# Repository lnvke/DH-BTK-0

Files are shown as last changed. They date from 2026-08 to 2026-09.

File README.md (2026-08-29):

# DH-BTK-0
Bluetooth keyboard HID device.

Made this so I can have a wireless keyboard while practicing with ESP-IDF BLE. Split would have given me the opportunity to work with peripheral bluetooth and non-HID communications, something I have never done before.

This is a custom integrated ESP32-C6 SoM based split keyboard using RMK rust mechanical keyboard firmware. Because Zephyr RTOS support for the ESP32-C6 is limited, ZMK firmware is not a viable choice for this project, as the HID (human interface) over GATT protocol has been documented to have conflicts between NimBLE and proprietary Espressif BLE controllers. RMK uses TrouBLE, a rust-based BLE host stack for bluetooth general functionality, which allows for direct interface with esp-radio, taking the role of the connecting link between TrouBLE and the internal host controller interface for bluetooth.
CAD:
https://cad.onshape.com/documents/ec01e30260fb570aa777a2a3 


PCB/Schematic:


(higher quality in SVG)

To make this for yourself, simply download the gerber files found in the production folder (seen as zip files) and export to your fab of choice. I used JLCPCB here. This PCB was designed to be completely double-sided and interchangeable, as to cut down on PCB manufacturing costs. Using JLCPCB's PCB fab MOQ of 5, you can make up to 2 of these keyboards given you have enough components.

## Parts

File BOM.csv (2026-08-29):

item | link | reason | cost | count
u.FL to SMA | https://www.amazon.com/dp/B0D29JTYPK | antenna connector | $7.19 | 5
RP-SMA | https://www.amazon.com/dp/B09KLR18H5/ | antenna | $6.99 | 2
switches | https://www.amazon.com/dp/B0GV2FGCPX/ | for switching | $13.90 | 72
sockets | https://www.amazon.com/dp/B0BVH64NXR | for hotswapping | $10.99 | 70
keycaps | https://www.amazon.com/dp/B0F6L7QTG5/ | so i can press them | $12.99 | 121
Samsung Electro-Mechanics CL21B106KOQNNNE | https://www.lcsc.com/product-detail/C95841.html | passive | $0 | 20
YAGEO CC0805KRX7R9BB104 | https://www.lcsc.com/product-detail/C49678.html | passive | $1 | 60
Samsung Electro-Mechanics CL21B475KAFNNNE | https://www.lcsc.com/product-detail/C98195.html | passive | $1.83 | 30
LIZ CD4148WSP | https://www.lcsc.com/product-detail/C109001.html | passive | $2.02 | 100
UNI-ROYAL 0805W8F5101T5E | https://www.lcsc.com/product-detail/C27834.html | passive | $0.00 | 100
FOJAN FRC0805F1501TS | https://www.lcsc.com/product-detail/C2907216.html | passive | $0.03 | 100
UNI-ROYAL 0805W8F4700T5E | https://www.lcsc.com/product-detail/C17710.html | passive | $0.00 | 100
FOJAN FRC0805F1001TS | https://www.lcsc.com/product-detail/C2907232.html | passive | $0.31 | 100
FOJAN FRC0805F1002TS | https://www.lcsc.com/product-detail/C2907219.html | passive | $0.35 | 100
FOJAN FRC0805F4701TS | https://www.lcsc.com/product-detail/C2907264.html | passive | $0.30 | 100
C&K JS102011SAQN | https://www.lcsc.com/product-detail/C221660.html | Switch | $5.84 | 5
ALPSALPINE EC11E15244G1 | https://www.lcsc.com/product-detail/C370970.html | Rotary Encoder | $11.37 | 5
onsemi NCP1117ST33T3G | https://www.lcsc.com/product-detail/C26537.html | LDO for voltage regulation | $1.18 | 5
ST USBLC6-2SC6 | https://www.lcsc.com/product-detail/C7519.html | ESD protection | $0.92 | 5
ESPRESSIF ESP32-C6-MINI-1U-H4 | https://www.lcsc.com/product-detail/C20627095.html | MCU | $20.59 | 5
TI TVS1400DRVR | https://www.lcsc.com/product-detail/C1975229.html | Flat clamp TVS diode | $2.45 | 5
TI BQ24075RGTR | https://www.lcsc.com/product-detail/C15464.html | Battery Charging | $6.00 | 5
Global Connector Technology USB4510-03-1-A | https://www.lcsc.com/product-detail/C5815192.html | Midmount USB-C receptacle | $5.95 | 5
Megastar ZX-PZ1.0-1-16PZZ | https://www.lcsc.com/product-detail/C37328866.html | 16-Pin Bridge | $0.69 | 5
YONGYUTAI YLED0603B | https://www.lcsc.com/product-detail/C19171394.html | Blue indicator LED | $0.59 | 100
YONGYUTAI YLED0603G | https://www.lcsc.com/product-detail/C19273151.html | "Emerald Green" indicator LED | $0.59 | 100
YONGYUTAI YLED0603R | https://www.lcsc.com/product-detail/C19171390.html | Red indicator LED | $0.59 | 100
YONGYUTAI YLED0805Y | https://www.lcsc.com/product-detail/C20608785.html | Yellow indicator LED | $0.59 | 50
PCB | https://jlcpcb.com/ | kind of important | $46.99 | 1
 | total |  |  | $162.55

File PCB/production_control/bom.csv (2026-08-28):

Designator | Footprint | Quantity | Value | LCSC Part #
C1, C2, C7 | 0805 | 3 | 10u
C3, C4, C5 | 0805 | 3 | 100n
C6, C8, C9 | 0805 | 3 | 4.7u
D1, D2 | 0805 | 2 | LED
D3 | 0805 | 1 | MODE_IND
D4 | 0805 | 1 | BOOT_IND
D5 | 0805 | 1 | TXRX_IND
J1 | GCT_USB4510-03-1-A_REVA | 1 | USB_C_Receptacle_USB2.0_16P
J2 | PinHeader_1x02_P2.54mm_Vertical | 1 | Battery
J3 | PinHeader_1x16_P1.00mm_Vertical | 1 | Conn_01x16_Pin
R1, R2 | 0805 | 2 | 5k1
R10, R12 | 0805 | 2 | 1k
R11 | 0805 | 1 | 4.7k
R13, R14, R15 | 0805 | 3 | 470
R3, R4, R5, R6, R8 | 0805 | 5 | 10k
R7 | 0805 | 1 | 27k
R9 | 0805 | 1 | 1.5k
SW1, SW2 | SW_JS102011SAQN | 2 | SW_SPDT
SW3 | SW_PUSH_1P1T_6x3.5mm_H4.3_APEM_MJTP1243 | 1 | EN
SW4 | SW_PUSH_1P1T_6x3.5mm_H4.3_APEM_MJTP1243 | 1 | BOOT
U1 | SOT-223-3_TabPin2 | 1 | NCP1117-3.3_SOT223
U2 | SOT-23-6 | 1 | USBLC6-2SC6
U3 | XCVR_ESP32-C6-MINI-1U-H4 | 1 | ESP32-C6-MINI-1
U4 | WSON-6-1EP_2x2mm_P0.65mm_EP1x1.6mm | 1 | TVS1400DRV
U5 | VQFN-16-1EP_3x3mm_P0.5mm_EP1.6x1.6mm | 1 | BQ24075RGT

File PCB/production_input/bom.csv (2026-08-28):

Designator | Footprint | Quantity | Value | LCSC Part #
D10, D11, D12, D13, D14, D15, D16, D17, D18, D19, D20, D21, D22, D23, D24, D25, D26, D27, D28, D29, D30, D31, D32, D33, D34, D35, D6, D7, D8, D9 | 0805 | 30 | D
J4 | PinHeader_1x16_P1.00mm_Vertical | 1 | Conn_01x16_Socket
SW10 | Kailh_socket_MX_reversible | 1 | 5,1
SW11 | Kailh_socket_MX_reversible | 1 | 6,1
SW12 | Kailh_socket_MX_reversible | 1 | 1,2
SW13 | Kailh_socket_MX_reversible | 1 | 2,2
SW14 | Kailh_socket_MX_reversible | 1 | 3,2
SW15 | Kailh_socket_MX_reversible | 1 | 4,2
SW16 | Kailh_socket_MX_reversible | 1 | 5,2
SW17 | Kailh_socket_MX_reversible | 1 | 6,2
SW18 | Kailh_socket_MX_reversible | 1 | 1,3
SW19 | Kailh_socket_MX_reversible | 1 | 2,3
SW20 | Kailh_socket_MX_reversible | 1 | 3,3
SW21 | Kailh_socket_MX_reversible | 1 | 4,3
SW22 | Kailh_socket_MX_reversible | 1 | 5,3
SW23 | Kailh_socket_MX_reversible | 1 | 6,3
SW24, SW30 | Kailh_socket_MX_reversible | 2 | 1,4
SW25, SW31 | Kailh_socket_MX_reversible | 2 | 2,4
SW26, SW32 | Kailh_socket_MX_reversible | 2 | 3,4
SW27, SW33 | Kailh_socket_MX_reversible | 2 | 4,4
SW28, SW34 | Kailh_socket_MX_reversible | 2 | 5,4
SW29, SW35 | Kailh_socket_MX_reversible | 2 | 6,4
SW5 | RotaryEncoder_Alps_EC12E-Switch_Vertical_H20mm_CircularMountingHoles | 1 | RotaryEncoder_Switch_MP
SW6 | Kailh_socket_MX_reversible | 1 | 1,1
SW7 | Kailh_socket_MX_reversible | 1 | 2,1
SW8 | Kailh_socket_MX_reversible | 1 | 3,1
SW9 | Kailh_socket_MX_reversible | 1 | 4,1

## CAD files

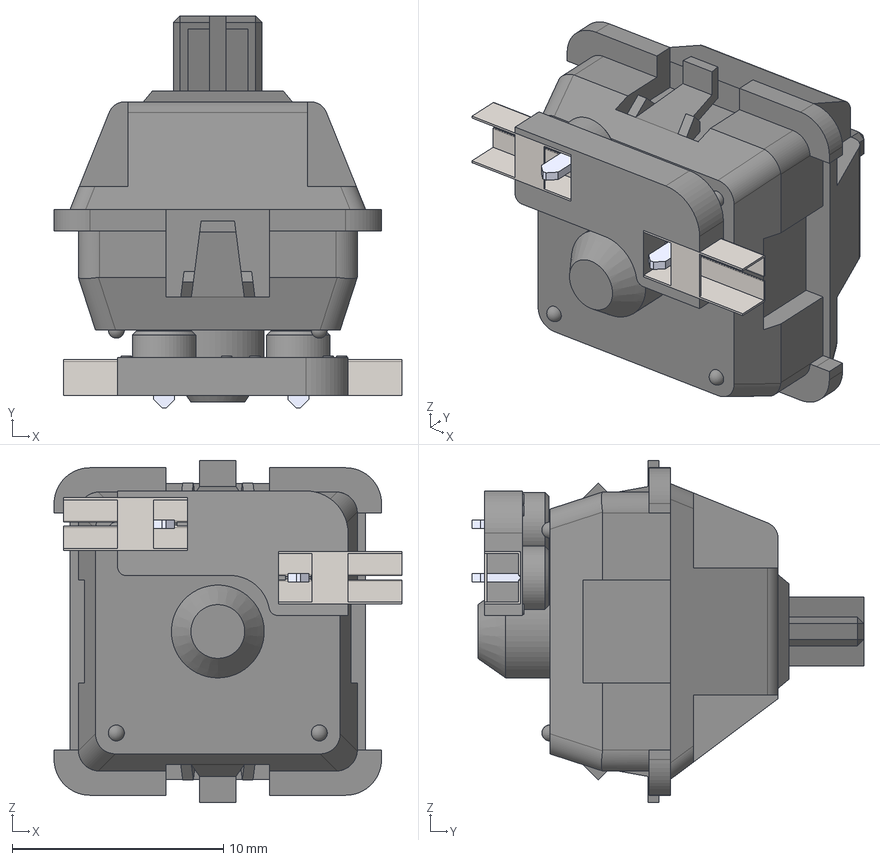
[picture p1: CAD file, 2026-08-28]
Footprints/fullhotswapswitchassembly.step
16.5 x 18.5 x 16.2 mm
Kailh Hotswap MX Inlay 2__Fillet3
Mirror1
Kailh Hotswap MX__Cut-Extrude2
Cut-Extrude5
Kailh Hotswap MX Inlay__Fillet3

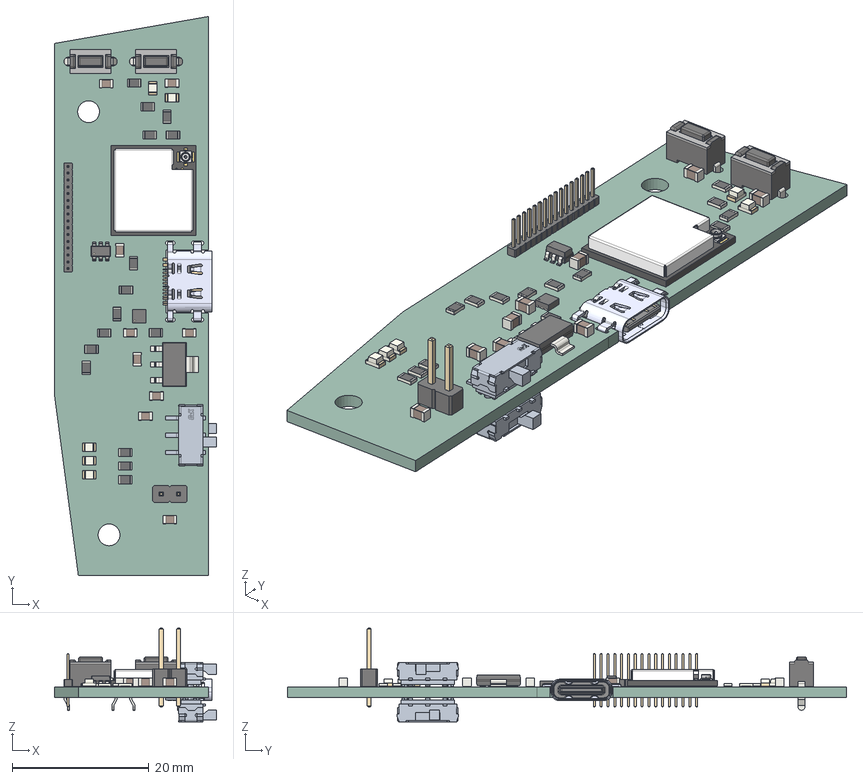
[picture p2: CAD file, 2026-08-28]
CAD SPLIT/STEP FILES/LEFTCONTROL.step
23.8 x 81.9 x 13.7 mm
R_0805_2012Metric x 15
SOT-23-6
LED_0805_2012Metric x 5
C_0805_2012Metric x 9
uid__2428
ipx3.xtd
R0201_20210301.xtd x 3
L0201_20210301.xtd x 2
C0201_20210301.xtd x 10
C0402_20210301.xtd
DFN1006.xtd
XTAL3225_20210301.xtd
ESP32-C6_QFN32_5X5_202306.xtd
placementOutline
Imported
C3-MINI-solder_pad
ShieldBox_ESP32-C3-MINI-1U_V1.0_20201210
PinHeader_1x02_P254mm_Vertical
USB4520-03-1-A
JS102011SAQN_SW0004_PRT x 2
SW_PUSH_1P1T_6x3.5mm_H4.3_APEM_MJTP1243 x 2
WSON_6_1EP_2x2mm_P065mm_EP1x16mm
PinHeader_1x16_P100mm_Vertical
SOT-223
LEFTCONTROL-unsaved-export-dA6rzE_PCB

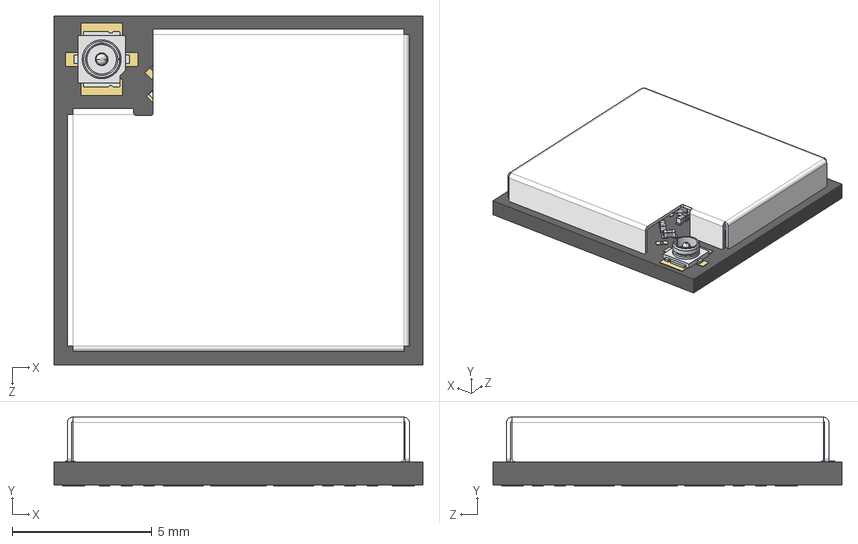
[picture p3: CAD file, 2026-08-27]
ESP32-C6-MINI-1U.step
13.2 x 2.47 x 12.5 mm
uid__2428
ipx3.xtd
R0201_20210301.xtd x 3
L0201_20210301.xtd x 2
C0201_20210301.xtd x 10
C0402_20210301.xtd
DFN1006.xtd
XTAL3225_20210301.xtd
ESP32-C6_QFN32_5X5_202306.xtd
placementOutline
Imported
C3-MINI-solder_pad
ShieldBox_ESP32-C3-MINI-1U_V1.0_20201210

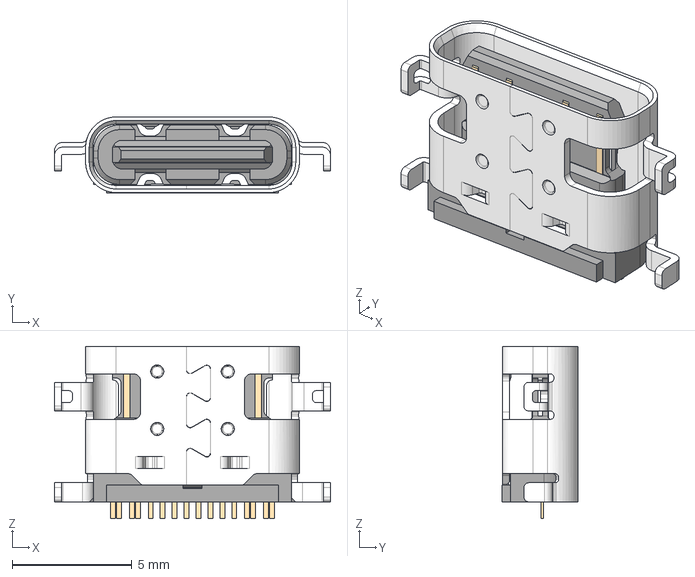
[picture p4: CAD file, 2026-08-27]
Footprints/USB4510_03_1_A/usb4510-03-1-a.stp
11.5 x 3.18 x 7.20 mm

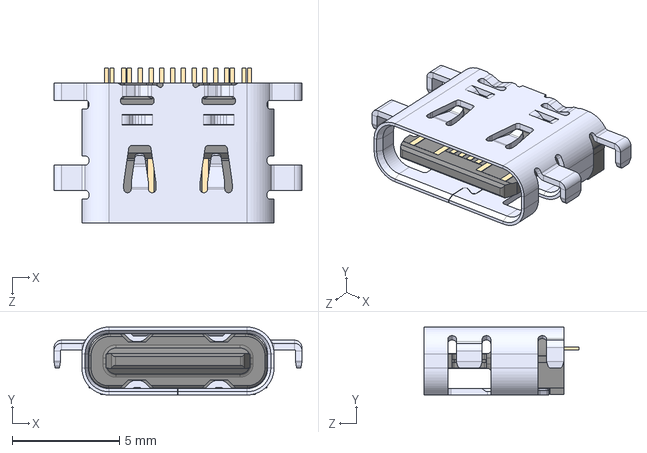
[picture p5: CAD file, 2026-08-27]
Footprints/USB4520_03_1_A/USB4520-03-1-A_REVA.step
11.5 x 3.16 x 7.20 mm

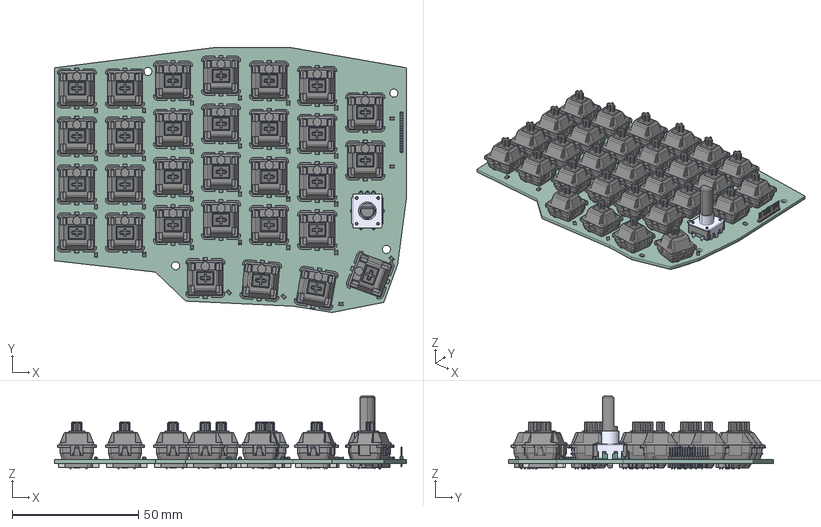
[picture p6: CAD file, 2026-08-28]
CAD SPLIT/STEP FILES/LEFTINPUT.step
139.5 x 105.0 x 28.8 mm
Kailh Hotswap MX Inlay 2__Fillet3 x 30
Mirror1 x 30
Kailh Hotswap MX__Cut-Extrude2 x 30
Cut-Extrude5 x 30
Kailh Hotswap MX Inlay__Fillet3 x 30
D_0805 x 30
PEC12R-4225F-S0024
PinHeader_1x16_P100mm_Vertical
LEFTINPUT-unsaved-export-xwXbsR_PCB

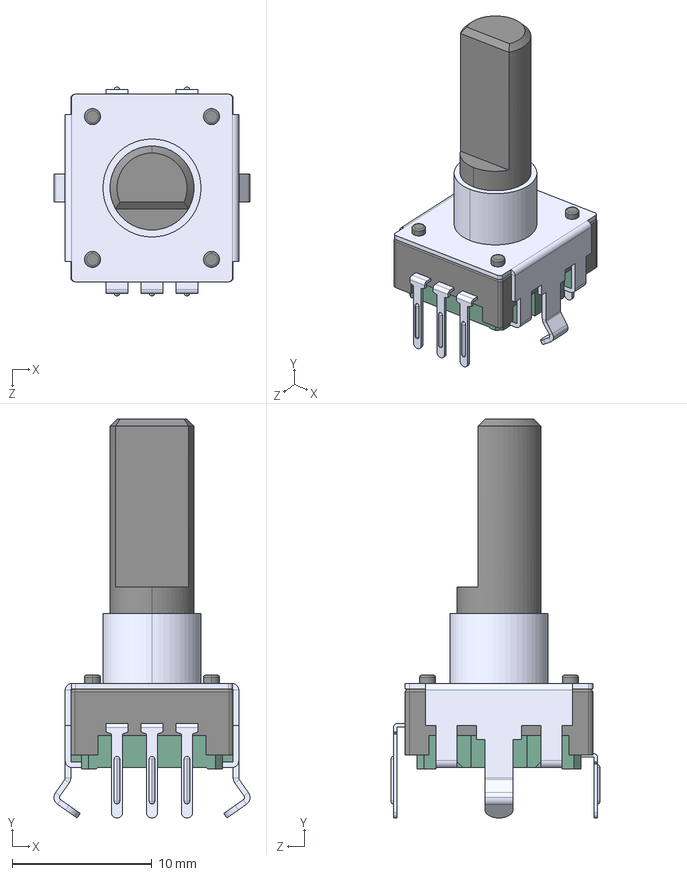
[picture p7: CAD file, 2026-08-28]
Footprints/PEC12R-4225F-S0024.STEP
14.0 x 28.5 x 14.9 mm

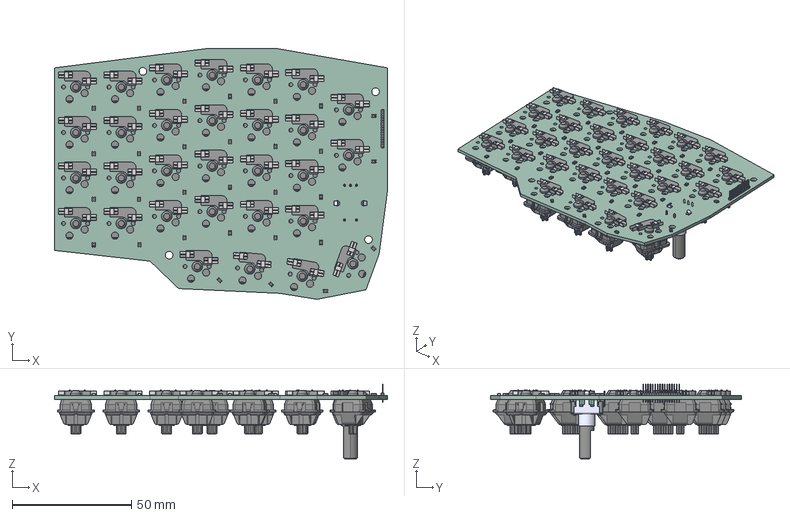
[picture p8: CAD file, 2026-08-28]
CAD SPLIT/STEP FILES/RIGHTINPUT.STEP
139.5 x 105.0 x 31.4 mm
Kailh Hotswap MX Inlay 2__Fillet3 x 30
Mirror1 x 30
Kailh Hotswap MX__Cut-Extrude2 x 30
Cut-Extrude5 x 30
Kailh Hotswap MX Inlay__Fillet3 x 30
D_0805 x 30
PEC12R-4225F-S0024
PinHeader_1x16_P100mm_Vertical
RIGHTINPUT-unsaved-export-6e6jIa_PCB

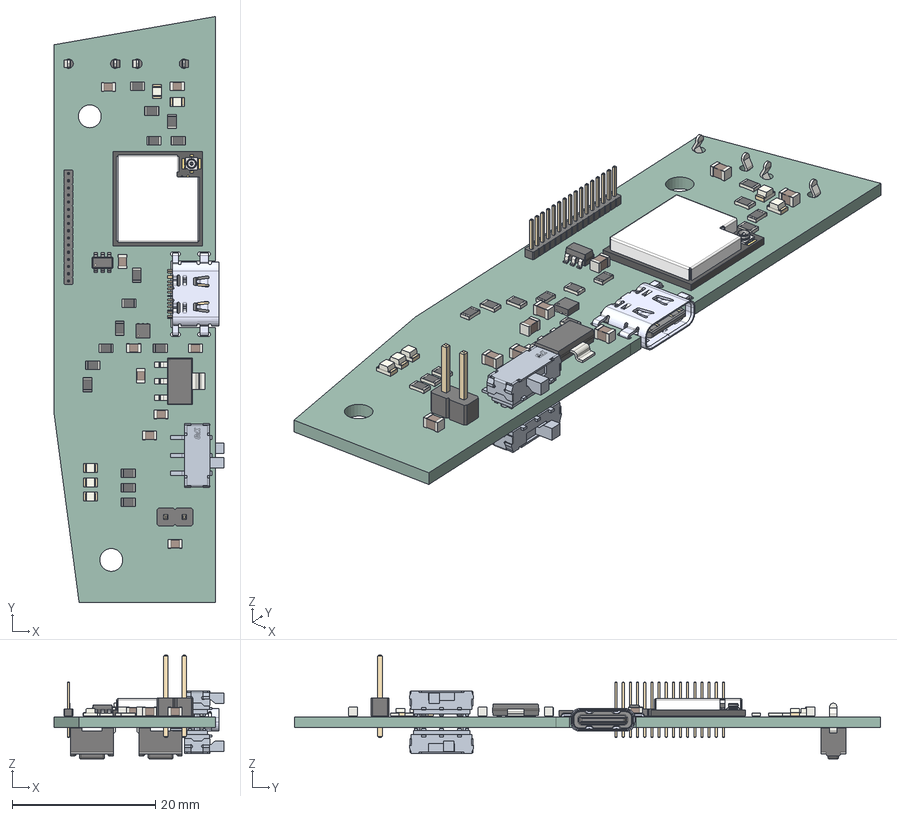
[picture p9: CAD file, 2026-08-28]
CAD SPLIT/STEP FILES/RIGHTCONTROL.step
23.8 x 81.9 x 14.5 mm
R_0805_2012Metric x 15
SOT-23-6
LED_0805_2012Metric x 5
C_0805_2012Metric x 9
uid__2428
ipx3.xtd
R0201_20210301.xtd x 3
L0201_20210301.xtd x 2
C0201_20210301.xtd x 10
C0402_20210301.xtd
DFN1006.xtd
XTAL3225_20210301.xtd
ESP32-C6_QFN32_5X5_202306.xtd
placementOutline
Imported
C3-MINI-solder_pad
ShieldBox_ESP32-C3-MINI-1U_V1.0_20201210
PinHeader_1x02_P254mm_Vertical
USB4520-03-1-A
JS102011SAQN_SW0004_PRT x 2
WSON_6_1EP_2x2mm_P065mm_EP1x16mm
PinHeader_1x16_P100mm_Vertical
SOT-223
SW_PUSH_1P1T_6x3.5mm_H4.3_APEM_MJTP1243 x 2
RIGHTCONTROL-unsaved-export-YBfufD_PCB

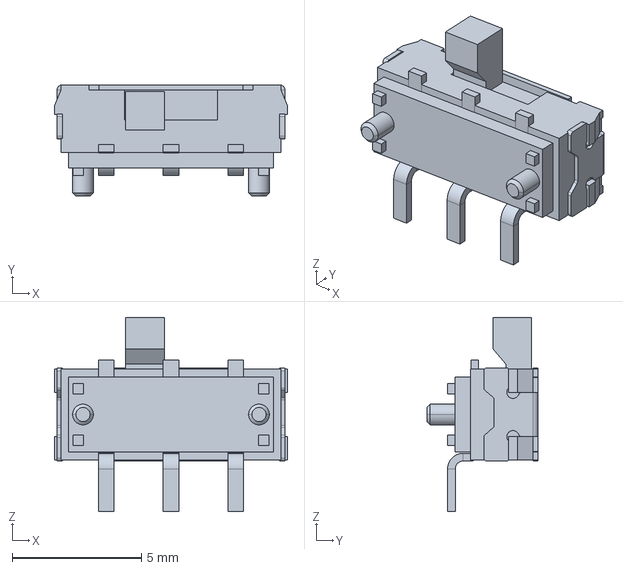
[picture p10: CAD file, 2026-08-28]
Footprints/JS102011SAQN/JS102011SAQN.step
9.00 x 4.30 x 7.50 mm

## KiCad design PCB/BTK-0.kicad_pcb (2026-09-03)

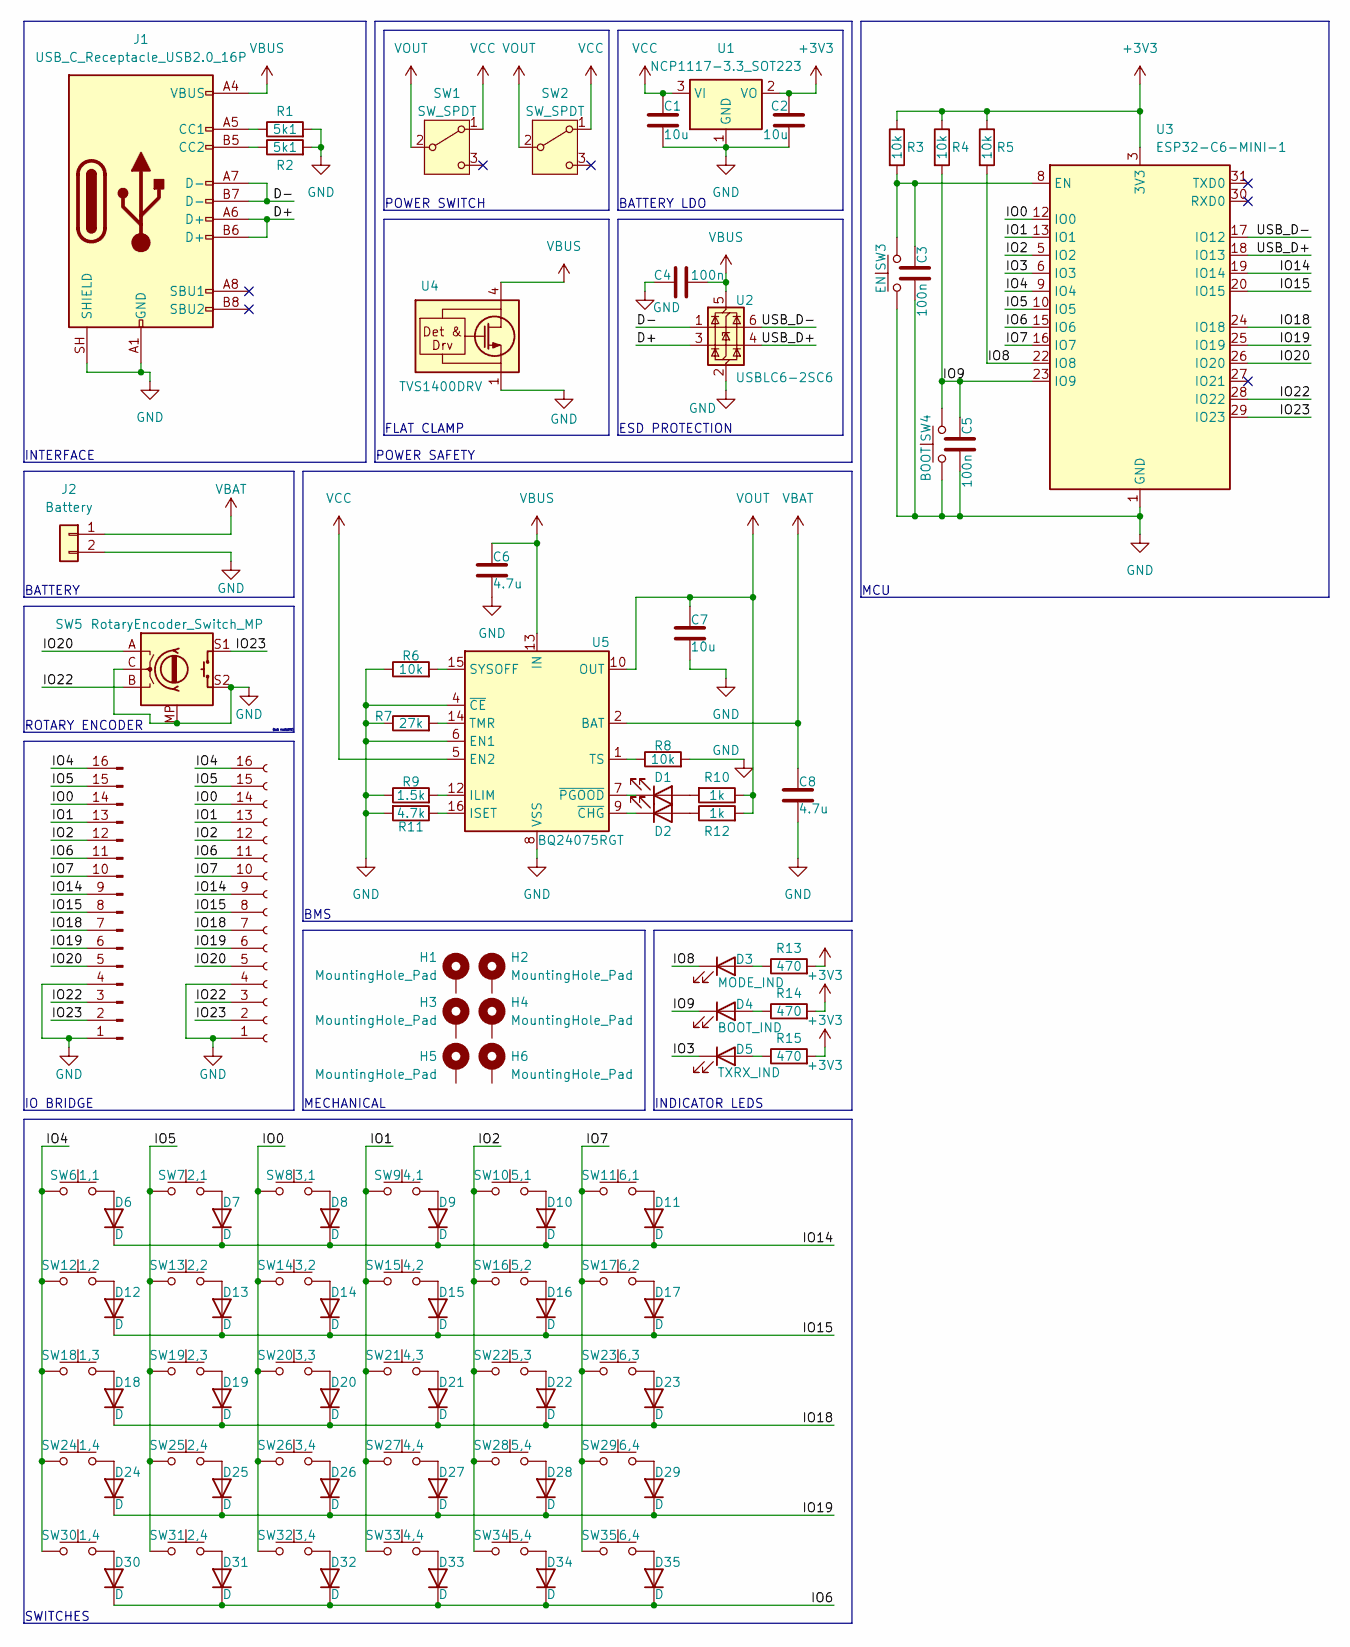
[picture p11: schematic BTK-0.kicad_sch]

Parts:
C1, C2, C7: 10u; C_0805_2012Metric
C3, C4, C5: 100n; C_0805_2012Metric
C6, C8: 4.7u; C_0805_2012Metric
D1, D2: LED; LED_0805_2012Metric
D3: MODE_IND; LED_0805_2012Metric
D4: BOOT_IND; LED_0805_2012Metric
D5: TXRX_IND; LED_0805_2012Metric
D6, D7, D8, D9, D10, D11, D12, D13, D14, D15, D16, D17, D18, D19, D20, D21, D22, D23, D24, D25, D26, D27, D28, D29, D30, D31, D32, D33, D34, D35: D; D_0805_2012Metric
H1, H2, H3, H4, H5, H6: MountingHole_Pad; MountingHole_3.2mm_M3_ISO7380
J1: USB_C_Receptacle_USB2.0_16P; GCT_USB4510-03-1-A_REVA
J2: Battery; PinHeader_1x02_P2.54mm_Vertical
J3: Conn_01x16_Pin; PinHeader_1x16_P1.00mm_Vertical
J4: Conn_01x16_Socket; PinHeader_1x16_P1.00mm_Vertical
R1, R2: 5k1; R_0805_2012Metric
R3, R4, R5, R6, R8: 10k; R_0805_2012Metric
R7: 27k; R_0805_2012Metric
R9: 1.5k; R_0805_2012Metric
R10, R12: 1k; R_0805_2012Metric
R11: 4.7k; R_0805_2012Metric
R13, R14, R15: 470; R_0805_2012Metric
SW1, SW2: SW_SPDT; SW_JS102011SAQN
SW3: EN; SW_Tactile_Straight_KSA0Axx1LFTR
SW4: BOOT; SW_PUSH_6mm
SW5: RotaryEncoder_Switch_MP; RotaryEncoder_Alps_EC12E-Switch_Vertical_H20mm_CircularMoun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
SW6: 1,1; Kailh_socket_MX_reversible
SW7: 2,1; Kailh_socket_MX_reversible
SW8: 3,1; Kailh_socket_MX_reversible
SW9: 4,1; Kailh_socket_MX_reversible
SW10: 5,1; Kailh_socket_MX_reversible
SW11: 6,1; Kailh_socket_MX_reversible
SW12: 1,2; Kailh_socket_MX_reversible
SW13: 2,2; Kailh_socket_MX_reversible
SW14: 3,2; Kailh_socket_MX_reversible
SW15: 4,2; Kailh_socket_MX_reversible
SW16: 5,2; Kailh_socket_MX_reversible
SW17: 6,2; Kailh_socket_MX_reversible
SW18: 1,3; Kailh_socket_MX_reversible
SW19: 2,3; Kailh_socket_MX_reversible
SW20: 3,3; Kailh_socket_MX_reversible
SW21: 4,3; Kailh_socket_MX_reversible
SW22: 5,3; Kailh_socket_MX_reversible
SW23: 6,3; Kailh_socket_MX_reversible
SW24, SW30: 1,4; Kailh_socket_MX_reversible
SW25, SW31: 2,4; Kailh_socket_MX_reversible
SW26, SW32: 3,4; Kailh_socket_MX_reversible
SW27, SW33: 4,4; Kailh_socket_MX_reversible
SW28, SW34: 5,4; Kailh_socket_MX_reversible
SW29, SW35: 6,4; Kailh_socket_MX_reversible
U1: NCP1117-3.3_SOT223; SOT-223-3_TabPin2
U2: USBLC6-2SC6; SOT-23-6
U3: ESP32-C6-MINI-1; XCVR_ESP32-C6-MINI-1U-H4
U4: TVS1400DRV; WSON-6-1EP_2x2mm_P0.65mm_EP1x1.6mm
U5: BQ24075RGT; VQFN-16-1EP_3x3mm_P0.5mm_EP1.6x1.6mm

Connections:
+3V3: C2.1, R3.1, R4.1, R5.1, R13.2, R14.2, R15.2, U1.2 (VO), U3.3 (3V3)
/D+: J1.A6 (D+), J1.B6 (D+), U2.3 (I/O2)
/D-: J1.A7 (D-), J1.B7 (D-), U2.1 (I/O1)
/IO0: J3.14, J4.14, SW8.1, SW14.1, SW20.1, SW26.1, SW32.1, U3.12 (IO0)
/IO1: J3.13, J4.13, SW9.1, SW15.1, SW21.1, SW27.1, SW33.1, U3.13 (IO1)
/IO2: J3.12, J4.12, SW10.1, SW16.1, SW22.1, SW28.1, SW34.1, U3.5 (IO2)
/IO3: D5.1 (K), U3.6 (IO3)
/IO4: J3.16, J4.16, SW6.1, SW12.1, SW18.1, SW24.1, SW30.1, U3.9 (IO4)
/IO5: J3.15, J4.15, SW7.1, SW13.1, SW19.1, SW25.1, SW31.1, U3.10 (IO5)
/IO6: D30.1 (K), D31.1 (K), D32.1 (K), D33.1 (K), D34.1 (K), D35.1 (K), J3.11, J4.11, U3.15 (IO6)
/IO7: J3.10, J4.10, SW11.1, SW17.1, SW23.1, SW29.1, SW35.1, U3.16 (IO7)
/IO8: D3.1 (K), R5.2, U3.22 (IO8)
/IO9: C5.1, D4.1 (K), R4.2, SW4.2, U3.23 (IO9)
/IO14: D6.1 (K), D7.1 (K), D8.1 (K), D9.1 (K), D10.1 (K), D11.1 (K), J3.9, J4.9, U3.19 (IO14)
/IO15: D12.1 (K), D13.1 (K), D14.1 (K), D15.1 (K), D16.1 (K), D17.1 (K), J3.8, J4.8, U3.20 (IO15)
/IO18: D18.1 (K), D19.1 (K), D20.1 (K), D21.1 (K), D22.1 (K), D23.1 (K), J3.7, J4.7, U3.24 (IO18)
/IO19: D24.1 (K), D25.1 (K), D26.1 (K), D27.1 (K), D28.1 (K), D29.1 (K), J3.6, J4.6, U3.25 (IO19)
/IO20: J3.5, J4.5, SW5.A, U3.26 (IO20)
/IO22: J3.3, J4.3, SW5.B, U3.28 (IO22)
/IO23: J3.2, J4.2, SW5.S1, U3.29 (IO23)
/USB_D+: U2.4 (I/O2), U3.18 (IO13)
/USB_D-: U2.6 (I/O1), U3.17 (IO12)
GND: C1.2, C2.2, C3.2, C4.1, C5.2, C6.2, C7.2, C8.2, J1.A1 (GND), J1.A12 (GND), J1.B1 (GND), J1.B12 (GND), J1.SH (SHIELD), J2.2, J3.1, J3.4, J4.1, J4.4, R1.2, R2.2, R6.1, R7.1, R8.2, R9.1, R11.2, SW3.1, SW4.1, SW5.C, SW5.MP, SW5.S2, U1.1 (GND), U2.2 (GND), U3.1 (GND), U3.2 (GND), U3.11 (GND), U3.14 (GND), U3.36 (GND), U3.37 (GND), U3.38 (GND), U3.39 (GND), U3.40 (GND), U3.41 (GND), U3.42 (GND), U3.43 (GND), U3.44 (GND), U3.45 (GND), U3.46 (GND), U3.47 (GND), U3.48 (GND), U3.49 (GND), U3.49_1 (GND), U3.49_2 (GND), U3.49_3 (GND), U3.49_4 (GND), U3.49_5 (GND), U3.49_6 (GND), U3.49_7 (GND), U3.49_8 (GND), U3.49_9 (GND), U3.50 (GND), U3.51 (GND), U3.52 (GND), U3.53 (GND), U4.1 (GND), U4.2 (GND), U4.3 (GND), U4.7 (GND), U5.4 (~CE), U5.6 (EN1), U5.8 (VSS), U5.17 (VSS); also elsewhere on the board
unnamed: D1.2 (A), R10.2
unnamed: D1.1 (K), U5.7 (~PGOOD)
unnamed: D2.2 (A), R12.1
unnamed: D2.1 (K), U5.9 (~CHG)
unnamed: D3.2 (A), R13.1
unnamed: D4.2 (A), R14.1
unnamed: D5.2 (A), R15.1
unnamed: D6.2 (A), SW6.2
unnamed: D7.2 (A), SW7.2
unnamed: D8.2 (A), SW8.2
unnamed: D9.2 (A), SW9.2
unnamed: D10.2 (A), SW10.2
unnamed: D11.2 (A), SW11.2
unnamed: D12.2 (A), SW12.2
unnamed: D13.2 (A), SW13.2
unnamed: D14.2 (A), SW14.2
unnamed: D15.2 (A), SW15.2
unnamed: D16.2 (A), SW16.2
unnamed: D17.2 (A), SW17.2
unnamed: D18.2 (A), SW18.2
unnamed: D19.2 (A), SW19.2
unnamed: D20.2 (A), SW20.2
unnamed: D21.2 (A), SW21.2
unnamed: D22.2 (A), SW22.2
unnamed: D23.2 (A), SW23.2
unnamed: D24.2 (A), SW24.2
unnamed: D25.2 (A), SW25.2
unnamed: D26.2 (A), SW26.2
unnamed: D27.2 (A), SW27.2
unnamed: D28.2 (A), SW28.2
unnamed: D29.2 (A), SW29.2
unnamed: D30.2 (A), SW30.2
unnamed: D31.2 (A), SW31.2
unnamed: D32.2 (A), SW32.2
unnamed: D33.2 (A), SW33.2
unnamed: D34.2 (A), SW34.2
unnamed: D35.2 (A), SW35.2
unnamed: J1.A5 (CC1), R1.1
unnamed: J1.B5 (CC2), R2.1
unnamed: C3.1, R3.2, SW3.2, U3.8 (EN)
unnamed: R9.2, U5.12 (ILIM)
unnamed: R11.1, U5.16 (ISET)
unnamed: R6.2, U5.15 (SYSOFF)
unnamed: R7.2, U5.14 (TMR)
unnamed: R8.1, U5.1 (TS)
VBAT: C8.1, J2.1, U5.2 (BAT), U5.3 (BAT)
VBUS: C4.2, C6.1, J1.A4 (VBUS), J1.A9 (VBUS), J1.B4 (VBUS), J1.B9 (VBUS), U2.5 (VBUS), U4.4 (IN), U4.5 (IN), U4.6 (IN), U5.13 (IN)
VCC: C1.1, SW1.1 (A), SW2.1 (A), U1.3 (VI), U5.5 (EN2)
VOUT: C7.1, R10.1, R12.2, SW1.2 (B), SW2.2 (B), U5.10 (OUT), U5.11 (OUT); also elsewhere on the board

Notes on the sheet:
POWER SAFETY
IO BRIDGE
MCU
MECHANICAL
INDICATOR LEDS
ROTARY ENCODER
POWER SWITCH
ESD PROTECTION
(nah really???)
INTERFACE
SWITCHES
FLAT CLAMP
BATTERY
BATTERY LDO
BMS

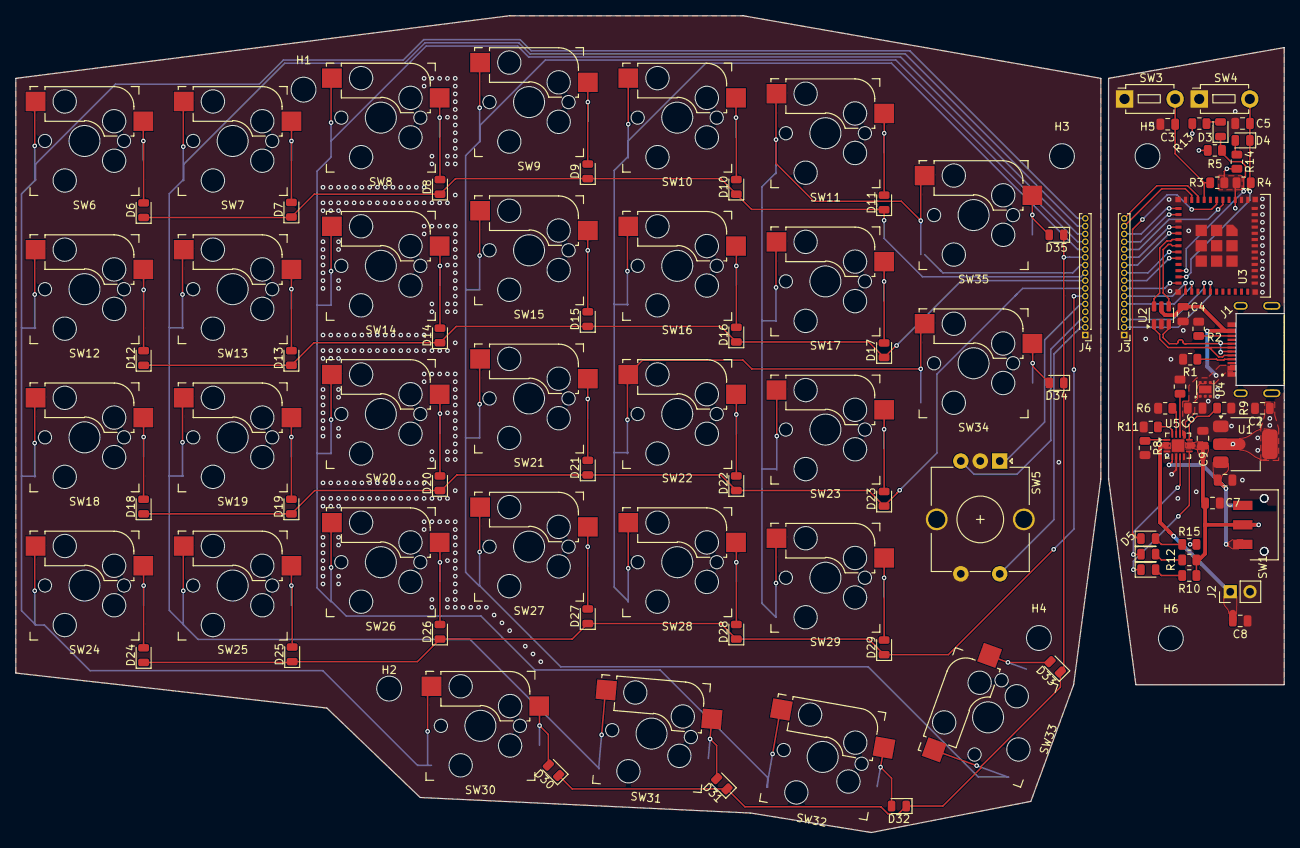
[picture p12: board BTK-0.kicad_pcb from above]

Board: 4 copper layers, 163.1 x 105.0 mm, 109 parts (1 on the bottom side), 72 nets.

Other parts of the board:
C9: 4.7u; C_0805_2012Metric

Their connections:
GND: C9.2; also elsewhere on the board
VOUT: C9.1; also elsewhere on the board

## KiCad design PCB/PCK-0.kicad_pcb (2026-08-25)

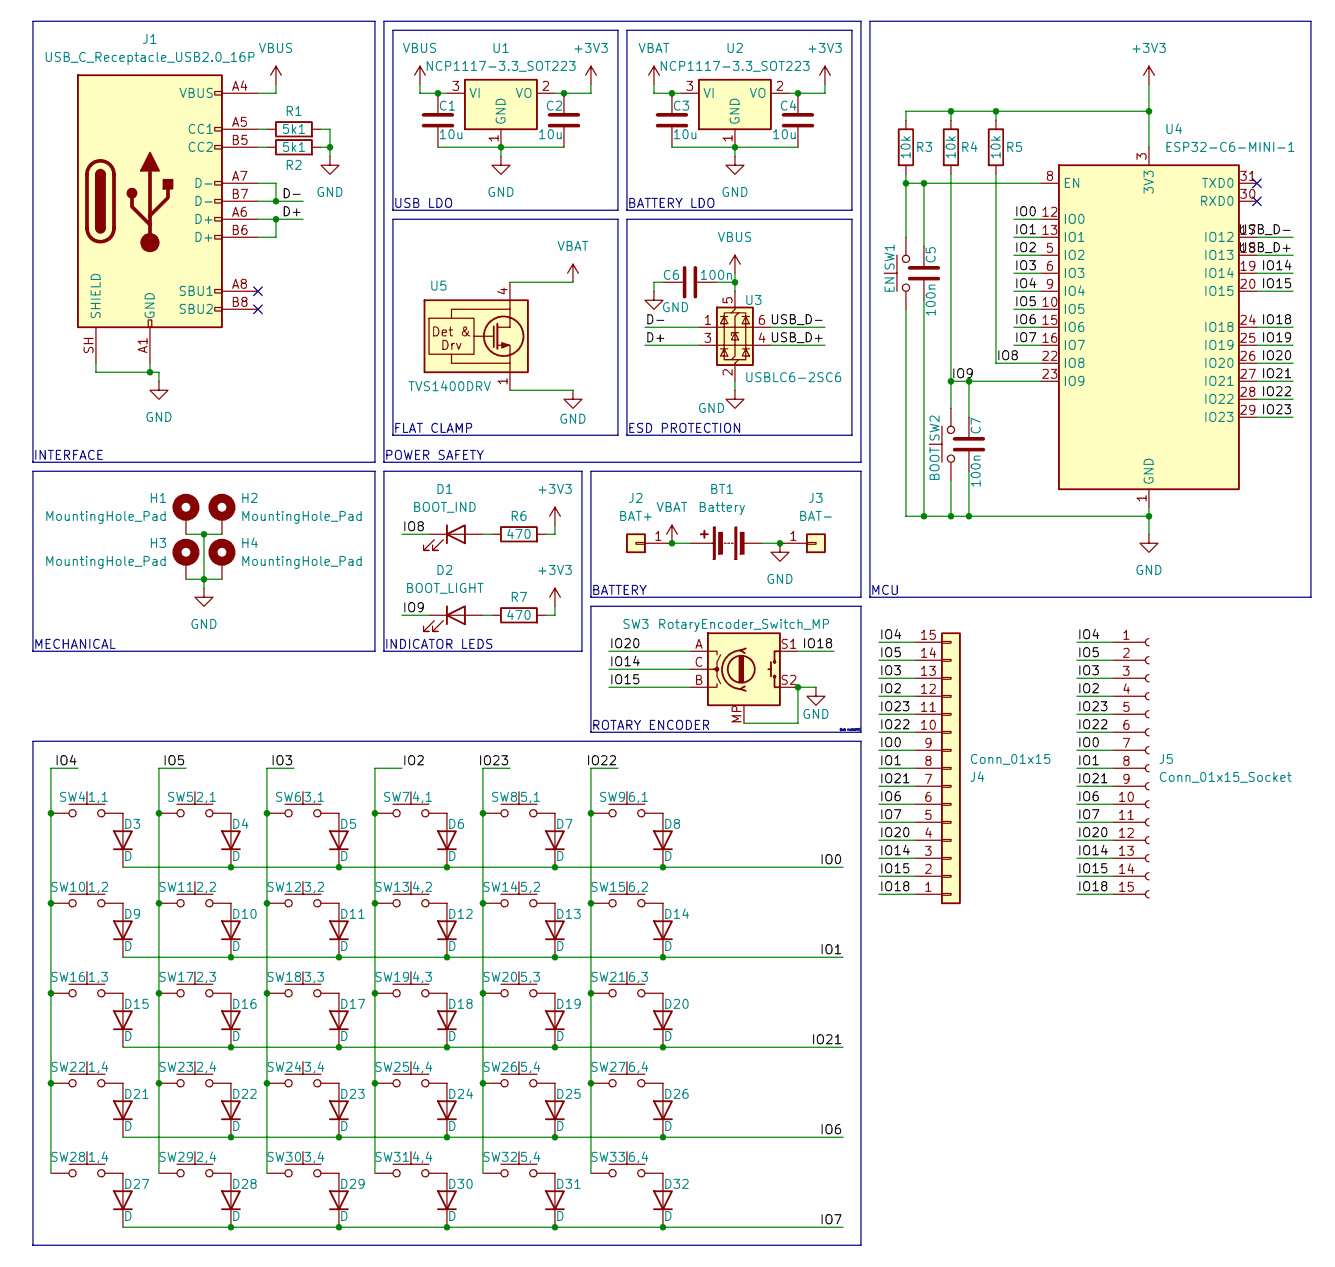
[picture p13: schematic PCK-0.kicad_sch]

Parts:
BT1: Battery; PinHeader_1x02_P2.54mm_Horizontal
C1, C2, C3, C4: 10u; C_0805_2012Metric
C5, C6, C7: 100n; C_0805_2012Metric
D1: BOOT_IND; D_0805_2012Metric
D2: BOOT_LIGHT; D_0805_2012Metric
D3, D4, D5, D6, D7, D8, D9, D10, D11, D12, D13, D14, D15, D16, D17, D18, D19, D20, D21, D22, D23, D24, D25, D26, D27, D28, D29, D30, D31, D32: D; D_0805_2012Metric
H1, H2, H3, H4: MountingHole_Pad; MountingHole_3.2mm_M3
J1: USB_C_Receptacle_USB2.0_16P; USB_C_Receptacle_GCT_USB4105-xx-A_16P_TopMnt_Horizontal
J2: BAT+; PinHeader_1x01_P2.54mm_Vertical
J3: BAT-; PinHeader_1x01_P2.54mm_Vertical
J4: Conn_01x15; PinHeader_1x15_P1.00mm_Horizontal
J5: Conn_01x15_Socket; PinSocket_1x15_P1.00mm_Vertical
R1, R2: 5k1; R_0603_1608Metric
R3, R4, R5: 10k; R_0603_1608Metric
R6, R7: 470; R_0603_1608Metric
SW1: EN; SW_Push_SPST_NO_Alps_SKRK
SW2: BOOT; SW_Push_SPST_NO_Alps_SKRK
SW3: RotaryEncoder_Switch_MP; RotaryEncoder_Alps_EC12E-Switch_Vertical_H20mm_CircularMoun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
SW4: 1,1; SW_MX_reversible
SW5: 2,1; SW_MX_reversible
SW6: 3,1; SW_MX_reversible
SW7: 4,1; SW_MX_reversible
SW8: 5,1; SW_MX_reversible
SW9: 6,1; SW_MX_reversible
SW10: 1,2; SW_MX_reversible
SW11: 2,2; SW_MX_reversible
SW12: 3,2; SW_MX_reversible
SW13: 4,2; SW_MX_reversible
SW14: 5,2; SW_MX_reversible
SW15: 6,2; SW_MX_reversible
SW16: 1,3; SW_MX_reversible
SW17: 2,3; SW_MX_reversible
SW18: 3,3; SW_MX_reversible
SW19: 4,3; SW_MX_reversible
SW20: 5,3; SW_MX_reversible
SW21: 6,3; SW_MX_reversible
SW22, SW28: 1,4; SW_MX_reversible
SW23, SW29: 2,4; SW_MX_reversible
SW24, SW30: 3,4; SW_MX_reversible
SW25, SW31: 4,4; SW_MX_reversible
SW26, SW32: 5,4; SW_MX_reversible
SW27, SW33: 6,4; SW_MX_reversible
U1, U2: NCP1117-3.3_SOT223; SOT-223-3_TabPin2
U3: USBLC6-2SC6; SOT-23-6
U4: ESP32-C6-MINI-1; XCVR_ESP32-C6-MINI-1U-H4
U5: TVS1400DRV; WSON-6-1EP_2x2mm_P0.65mm_EP1x1.6mm

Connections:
+3V3: C2.1, C4.1, R3.1, R4.1, R5.1, R6.2, R7.2, U1.2 (VO), U2.2 (VO), U4.3 (3V3)
/D+: J1.A6 (D+), J1.B6 (D+), U3.3 (I/O2)
/D-: J1.A7 (D-), J1.B7 (D-), U3.1 (I/O1)
/IO0: D3.1 (K), D4.1 (K), D5.1 (K), D6.1 (K), D7.1 (K), D8.1 (K), J4.9, J5.7, U4.12 (IO0)
/IO1: D9.1 (K), D10.1 (K), D11.1 (K), D12.1 (K), D13.1 (K), D14.1 (K), J4.8, J5.8, U4.13 (IO1)
/IO2: J4.12, J5.4, SW7.1, SW13.1, SW19.1, SW25.1, SW31.1, U4.5 (IO2)
/IO3: J4.13, J5.3, SW6.1, SW12.1, SW18.1, SW24.1, SW30.1, U4.6 (IO3)
/IO4: J4.15, J5.1, SW4.1, SW10.1, SW16.1, SW22.1, SW28.1, U4.9 (IO4)
/IO5: J4.14, J5.2, SW5.1, SW11.1, SW17.1, SW23.1, SW29.1, U4.10 (IO5)
/IO6: D21.1 (K), D22.1 (K), D23.1 (K), D24.1 (K), D25.1 (K), D26.1 (K), J4.6, J5.10, U4.15 (IO6)
/IO7: D27.1 (K), D28.1 (K), D29.1 (K), D30.1 (K), D31.1 (K), D32.1 (K), J4.5, J5.11, U4.16 (IO7)
/IO8: D1.1 (K), R5.2, U4.22 (IO8)
/IO9: C7.1, D2.1 (K), R4.2, SW2.2, U4.23 (IO9)
/IO14: J4.3, J5.13, SW3.C, U4.19 (IO14)
/IO15: J4.2, J5.14, SW3.B, U4.20 (IO15)
/IO18: J4.1, J5.15, SW3.S1, U4.24 (IO18)
/IO19: U4.25 (IO19)
/IO20: J4.4, J5.12, SW3.A, U4.26 (IO20)
/IO21: D15.1 (K), D16.1 (K), D17.1 (K), D18.1 (K), D19.1 (K), D20.1 (K), J4.7, J5.9, U4.27 (IO21)
/IO22: J4.10, J5.6, SW9.1, SW15.1, SW21.1, SW27.1, SW33.1, U4.28 (IO22)
/IO23: J4.11, J5.5, SW8.1, SW14.1, SW20.1, SW26.1, SW32.1, U4.29 (IO23)
/USB_D+: U3.4 (I/O2), U4.18 (IO13)
/USB_D-: U3.6 (I/O1), U4.17 (IO12)
GND: BT1.2 (-), C1.2, C2.2, C3.2, C4.2, C5.2, C6.1, C7.2, H1.1, H2.1, H3.1, H4.1, J1.A1 (GND), J1.A12 (GND), J1.B1 (GND), J1.B12 (GND), J1.SH (SHIELD), J3.1, R1.2, R2.2, SW1.1, SW2.1, SW3.MP, SW3.S2, U1.1 (GND), U2.1 (GND), U3.2 (GND), U4.1 (GND), U4.2 (GND), U4.11 (GND), U4.14 (GND), U4.36 (GND), U4.37 (GND), U4.38 (GND), U4.39 (GND), U4.40 (GND), U4.41 (GND), U4.42 (GND), U4.43 (GND), U4.44 (GND), U4.45 (GND), U4.46 (GND), U4.47 (GND), U4.48 (GND), U4.49 (GND), U4.49_1 (GND), U4.49_2 (GND), U4.49_3 (GND), U4.49_4 (GND), U4.49_5 (GND), U4.49_6 (GND), U4.49_7 (GND), U4.49_8 (GND), U4.49_9 (GND), U4.50 (GND), U4.51 (GND), U4.52 (GND), U4.53 (GND), U5.1 (GND), U5.2 (GND), U5.3 (GND), U5.7 (GND)
unnamed: D1.2 (A), R6.1
unnamed: D2.2 (A), R7.1
unnamed: D3.2 (A), SW4.2
unnamed: D4.2 (A), SW5.2
unnamed: D5.2 (A), SW6.2
unnamed: D6.2 (A), SW7.2
unnamed: D7.2 (A), SW8.2
unnamed: D8.2 (A), SW9.2
unnamed: D9.2 (A), SW10.2
unnamed: D10.2 (A), SW11.2
unnamed: D11.2 (A), SW12.2
unnamed: D12.2 (A), SW13.2
unnamed: D13.2 (A), SW14.2
unnamed: D14.2 (A), SW15.2
unnamed: D15.2 (A), SW16.2
unnamed: D16.2 (A), SW17.2
unnamed: D17.2 (A), SW18.2
unnamed: D18.2 (A), SW19.2
unnamed: D19.2 (A), SW20.2
unnamed: D20.2 (A), SW21.2
unnamed: D21.2 (A), SW22.2
unnamed: D22.2 (A), SW23.2
unnamed: D23.2 (A), SW24.2
unnamed: D24.2 (A), SW25.2
unnamed: D25.2 (A), SW26.2
unnamed: D26.2 (A), SW27.2
unnamed: D27.2 (A), SW28.2
unnamed: D28.2 (A), SW29.2
unnamed: D29.2 (A), SW30.2
unnamed: D30.2 (A), SW31.2
unnamed: D31.2 (A), SW32.2
unnamed: D32.2 (A), SW33.2
unnamed: J1.A5 (CC1), R1.1
unnamed: J1.B5 (CC2), R2.1
unnamed: C5.1, R3.2, SW1.2, U4.8 (EN)
VBAT: BT1.1 (+), C3.1, J2.1, U2.3 (VI), U5.4 (IN), U5.5 (IN), U5.6 (IN)
VBUS: C1.1, C6.2, J1.A4 (VBUS), J1.A9 (VBUS), J1.B4 (VBUS), J1.B9 (VBUS), U1.3 (VI), U3.5 (VBUS)

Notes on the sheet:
POWER SAFETY
MCU
MECHANICAL
INDICATOR LEDS
ROTARY ENCODER
USB LDO
ESD PROTECTION
(nah really???)
INTERFACE
FLAT CLAMP
BATTERY
BATTERY LDO

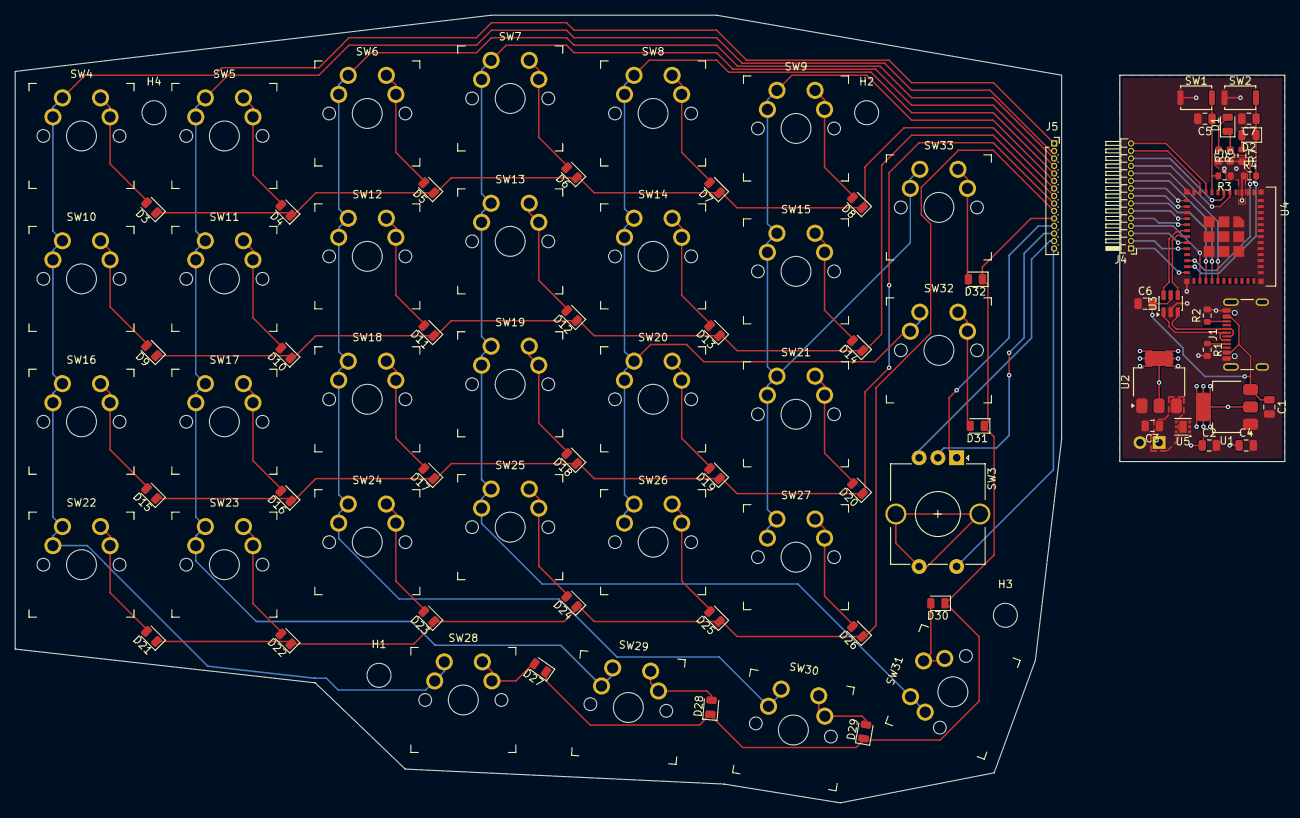
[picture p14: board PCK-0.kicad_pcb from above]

Board: 4 copper layers, 169.2 x 105.0 mm, 92 parts (1 on the bottom side), 60 nets.

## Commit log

2026-08-16 schematic start
    [PCK-0.kicad_sch]
2026-08-17 schematic done
    [PCK-0.kicad_pcb, emg.kicad_sch]
2026-08-17 pcb start
    [PCK-0.kicad_pcb, PCK-0.kicad_sch, emg.kicad_sch]
2026-08-18 pcb key layout done
    [PCK-0.kicad_pcb, PCK-0.kicad_sch]
2026-08-18 key layout rework
    [PCK-0.kicad_pcb, PCK-0.kicad_sch]
2026-08-19 ground plane and some power routing
    [PCK-0.kicad_pcb, PCK-0.kicad_sch]
2026-08-19 mcu placement rework, power zones
    [PCK-0.kicad_pcb, PCK-0.kicad_sch]
2026-08-19 file organization
    [PCK-0.kicad_pcb, PCK-0.kicad_sch, PCK_R.kicad_sch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]
2026-08-19 dont know lowkey
    [PCK-0.kicad_pcb]
2026-08-23 one must imagine sisyphus happy
    [PCK-0.kicad_pcb, PCK-0.kicad_sch]
2026-08-23 reformat + modular control scheme
    [PCK-0.kicad_pcb, PCK-0.kicad_sch]
2026-08-24 double sided probably works
    [PCK-0.kicad_pcb, PCK-0.kicad_sch]
2026-08-25 diode changed to SMD, mounting holes
    [PCK-0.kicad_pcb, PCK-0.kicad_sch, PCK-0_control_board.kicad_pcb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]
2026-08-25 separated control from input pcb
    [PCK-0.kicad_pcb]
2026-08-25 step exported
    [PCK-0_control_board.kicad_pcb, PCK-0_control_board.step, PCK-0_input_board.step]
2026-08-25 fixed naming + control board more symmetrical, mcu to pin remap + mounting hole on control board
    [BTK-0.kicad_pcb, BTK-0.kicad_sch, PCK-0.kicad_pcb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]
2026-08-25 fixing god knows what
    [BTK-0-inputPCB.kicad_pcb, BTK-0.kicad_pcb, BTK-0.kicad_sch]
2026-08-26 separate split pcb production files created
    [BTK-0.kicad_pcb, BTK-0_control.kicad_pcb, BTK-0_input.kicad_pcb]
2026-08-26 latest step files
    [BTK-0_control.kicad_pcb, BTK-0_control.step, BTK-0_input.kicad_pcb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]
2026-08-26 re-centered control cad
    [BTK-0_control.kicad_pcb, BTK-0_control.step]
2026-08-27 im boutta die son
    [BTK-0.kicad_sch, BTK-0_control.kicad_pcb, BTK-0_control.step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]
2026-08-27 we're so back
    [BTK-0.kicad_pcb, BTK-0.kicad_sch]
2026-08-27 i hate data collection
    [BTK-0.kicad_pcb, usb4510-03-1-a.stp]
2026-08-27 final DRC fixes
    [BTK-0.kicad_pcb, BTK-0.kicad_sch, USB4520-03-1-A_REVA.step]
2026-08-27 old switches rollback point
    [BTK-0-old.kicad_pcb, BTK-0.kicad_sch]
2026-08-28 new switches kailh sockets
    [BTK-0-old.kicad_pcb, BTK-0.kicad_pcb, BTK-0.kicad_sch]
2026-08-28 fixed power scheme, on/off switch to power
    [BTK-0.kicad_pcb]
2026-08-28 exported cad
    [BTK-0.kicad_pcb, BTK-0_control.kicad_pcb, BTK-0_control.step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]
2026-08-28 fixed rollback, alignment and powerswitch redone
    [BTK-0.kicad_pcb, BTK-0.kicad_sch, JS102011SAQN.step]
2026-08-28 right board done
    [LEFT.kicad_pcb, LEFT.kicad_sch, PEC12R-4225F-S0024.STEP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]
2026-08-28 left board, step files, and production files done
    [BTK-0.kicad_pcb, LEFT.kicad_pcb, LEFTCONTROL.kicad_pcb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]
2026-08-28 were so back fr this time
    [PRODUCTION_INPUT.kicad_pcb]
2026-08-29 BOM added
    [BOM.csv]
2026-08-29 BOM fix
    [BOM.csv]
2026-08-29 readme now has images for forge compliance
    Added CAD link and schematic images to README.
2026-08-29 Update Schematic section in README.md
2026-08-29 Update README with manufacturing instructions
    Added instructions for downloading gerber files and manufacturing details.
2026-08-29 BOM update
    [BOM.csv]
2026-09-03 fixing rotary encoder pin
    [BTK-0.kicad_pcb, BTK-0.kicad_sch, PRODUCTION_CONTROL.kicad_pcb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]
